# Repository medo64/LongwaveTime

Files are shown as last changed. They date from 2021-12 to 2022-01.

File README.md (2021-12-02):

[LongwaveTime](https://medo64.com/longwavetime/)
================================================

This USB device will show up on your system as a serial device and allow for
modulation of WWVB and DCF77 time synchronization signal using either onboard
or external antenna.

Actual antenna output stage is a variation on well-known [Radio time station
transmitter by Henner Zeller](https://github.com/hzeller/txtempus) setup which
sends the signal out with a bare minimum of components. Combine that rather
simplistic design with PCB antenna and you have yourself a really localized
device.

Mind you, this is by design as the primary use case for this device is
experimentation and it's not intended to compete with official WWVB or DCF77
signal. Onboard antenna should have enough power to work with watch on top of
it and no more.

Of course, with an external 60 kHz (WWVB) or 75 kHz (DCF77) antenna, signal will
propagate a bit further but you should really only consider this if your home
is not covered with official signal.

### Legality of WWVB transmission ###

Transmitting on unlicensed frequencies is quite often an issue and should be
taken seriously. In USA legality of the same is coverted in [Understanding the FCC Regulations for Low-Power Non-Licensed Transmitters](https://transition.fcc.gov/Bureaus/Engineering_Technology/Documents/bulletins/oet63/oet63rev.pdf).
Short version is that you can do so as long as you keep it under 40 μV/m
measured at 300 meters. This device with its internal antenna is going to be
way under this limit.

If you plan to use it with external antenna, things get a bit trickier. I like
to use NIST's [Estimated Seasonal Signal Strength of WWVB, µV/m](https://www.nist.gov/system/files/documents/calibrations/sp432-02.pdf)
as a rule-of-the-thumb reference and as long as your watch synchronization
works only up to 10 meteres or so, you will be way under 40 µV/m as required
by FCC's rules and really unlikely to be causing any interference.

But, regardless of the rules, under no circumstances should you interfere with
official WWVB signal. This might not be encoded in rules, but it should be a
common sense.

As far as legality in other countries goes, do your own research.

---
*You can check my blog and other projects at [www.medo64.com](https://medo64.com/electronics/).*

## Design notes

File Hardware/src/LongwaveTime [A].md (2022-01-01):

### Longwave Time Parts ###

|  # | Part | RefDes  | DigiKey Part Number | Alternative Part Number |
|---:|---|---|---|---|
|  3 | C 560pF X7R 16V (0805) | C1-C3 | 1276-1798-1-ND | 1276-1834-1-ND |
|  2 | C 330nF X7R 16V (0805) | C4-C5 | 732-7669-1-ND | 1276-1123-1-ND |
|  2 | DS LED (0805) | DS1-DS2 | 475-1278-1-ND | L171L-LWC-TR |
|  1 | J USB B, horizontal | J1 | ED2982-ND | ED2983-ND |
|  3 | R 470 0.125W (0805) | R1-R3 | RMCF0805FT470RCT-ND | RMCF0805JT470RCT-ND |
|  4 | R 5.1K 0.125W (0805) | R4-R7 | RMCF0805FT5K10CT-ND | RMCF0805JT5K10CT-ND |
|  1 | U PIC16F1454-I/SL (SOIC-14) | U1 | PIC16F1454-I/SL-ND | PIC16F1454T-I/SLCT-ND |
|  1 | H Enclosure 4.5x1.4x1.0" | | HM861-ND | 377-1653-ND |
|  4 | H PCB Screw Self-tapping M3 6mm (#4 1/4") | | | |

#### Board Size ####

| | Dimensions | Area | Thickness |
|---|---|---|---|
| PCB |  85.4 x 26.0 mm | 3.5 in² | 1.6 mm |
| Panel |  29.5 x 20.3 mm | 1.0 in² | 1.6 mm |

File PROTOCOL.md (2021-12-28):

### Longwave Time Protocol ###

This device presents itself as a serial port. Serial port parameters are
115200,N,8,1.

For purpose of protocol `<CR>` and `<LF>` end of line characters can be used
interchangeably. Each response will end with `<CR><LF>`. If command has no
arguments, it will return the current status.

Commands that resulted in error will always end in `!` `<BEL>` `<CR>` `<LF>`.

#### Set Protocol (P) #####

This command will set the protocol.

| | Text |
|---|---|
| Syntax | `P{1:protocol}<LF>` |
| Response | `P{1:protocol}<CR><LF>` |
| Reject | `P!<BEL><CR><LF>` |

The following protocol values are allowed:

| Value | Protocol |  Carrier | Frequency |
|:-----:|---|---:|---:|
| 0 | None | - | - |
| W | WWVB | 60.0 kHz | 60,000.00 Hz |
| D | DCF77 | 77.5 kHz | 77,419.35 Hz |
| M | MSF | 60.0 kHz | 60,000.00 Hz |
| 4 | JJY | 40.0 kHz | 40,000.00 Hz |
| 6 | JJY | 60.0 kHz | 60,000.00 Hz |

Please note that 77.5 kHz cannot be correctly represented by device without a
small carrier deviation. This does not impact auto-incrementing time but only
the carrier. All watches I tested with were able to tolerate this.

Here are some usage examples:

| Example | Send | Receive | Notes |
|---|---|---|---|
| Query | `P<LF>` | `PW<CR><LF>` | Using WWVB protocol |
| Set WWVB | `PW<LF>` | `PW<CR><LF>` | Set protocol to WWVB |
| Set DCF77 | `PD<LF>` | `PD<CR><LF>` | Set protocol to DCF77 |
| Turn off | `P0<LF>` | `P0<CR><LF>` | No carrier or time-keeping |
| Unknown protocol | `Px<LF>` | `F!<BEL><CR><LF>`  | |

#### Raw Data (R) #####

Sets bit data. Data is always set for the buffer not in use.

Buffers are called X and Y.

| | Text | Notes |
|---|---|---|
| Syntax | `R{59-61:data}<LF>` | |
| Response | `R{2:buffer}<CR><LF>` | Current buffer, followed by buffer user for command |
| Reject | `R!<BEL><CR><LF>` | |

If one sets 59 or 61 bit, leap second will be assumed.

Bits sets using this command superseed data set by any other command.

The following bits are supported for [WWVB](https://en.wikipedia.org/wiki/WWVB):

| Data  | Value | Description |
|:-----:|---|---|
| 0 | Bit 0 | 200 ms reduced power, 800 ms full power |
| 1 | Bit 1 | 500 ms full power, 500 ms reduced power |
| M | Marker | 800 ms reduced power, 200 ms full power |

The following bits are supported for [DCF77](https://en.wikipedia.org/wiki/DCF77):

| Data  | Value | Description |
|:-----:|---|---|
| 0 | Bit 0 | 100 ms reduced power, 900 ms full power |
| 1 | Bit 1 | 200 ms reduced power, 800 ms full power |
| M | Minute mark  | no amplitude modulation |

The following bits are supported for [MSF](https://en.wikipedia.org/wiki/Time_from_NPL_(MSF)):

| Data  | Value | Description |
|:-----:|---|---|
| 0 | Bits 00 | Carrier is encoded as follows _~~~~~~~~~ |
| 1 | Bits 01 | Carrier is encoded as follows _~_~~~~~~~ |
| 2 | Bits 10 | Carrier is encoded as follows __~~~~~~~~ |
| 3 | Bits 11 | Carrier is encoded as follows ___~~~~~~~ |
| M | Minute mark  | Carrier off for 500 ms, carrier on for 500 ms |

The following bits are supported for [JJY](https://en.wikipedia.org/wiki/JJY):

| Data  | Value | Description |
|:-----:|---|---|
| 0 | Bit 0 | 800 ms full power, 200 ms reduced power |
| 1 | Bit 1 | 500 ms full power, 500 ms reduced power |
| M | Marker | 200 ms full power, 800 ms reduced power |

Here are some usage examples:

| Example | Send | Receive | Notes |
|---|---|---|---|
| Query | `R<LF>` | `RYX<CR><LF>` | Buffer Y is currently in use and X is ready |
| Query | `R<LF>` | `RY~<CR><LF>` | Buffer Y is currently in use and no new buffer is ready |
| Set | `R123...<LF>` | `R~X<CR><LF>` | New data was written in buffer X and there was no current buffer |
| Not enough bits | `R011<LF>` | `R!<BEL><CR><LF>`  | Must have 59-61 bits (60 usually) |
| Unknown protocol | `Rx<LF>` | `R!<BEL><CR><LF>`  | |

#### Start (S) #####

This command will synchronize time and start sending data if one is not already
sent. Input can be given in either seconds or tenths of second while output is
always in tenths of second.

Buffer is always switched either when `S` is called or when a full minute has
elapsed.

| | Text |
|---|---|
| Syntax | `S{2-3:second}<LF>` |
| Response | `S{3:second}<CR><LF>` |
| Reject | `S!<BEL><CR><LF>` |

Second can be any number from 00-60.

Here are some usage examples:

| Example | Send | Receive | Notes |
|---|---|---|---|
| Query | `S<LF>` | `S103<CR><LF>` | Returns current tenth of a second (10.2s) |
| Query | `S<LF>` | `S---<CR><LF>` | Returning `-` when not active |
| Sync time | `S42<LF>` | `S420<CR><LF>` | Syncs device to second 42 |
| Unknown second | `S61<LF>` | `S!<BEL><CR><LF>`  | |

##### Test Mode (T) #####

Testing. To enter into test mode use `T**<LF>`.

| | Text |
|---|---|
| Syntax | `T<LF>` |
| Response | `T{1:command}<CR><LF>` |
| Reject | `T!<BEL><CR><LF>` |

Here are some usage examples:

| Example | Send | Receive | Notes |
|---|---|---|---|
| Query | `T<LF>` | `TWCa<CR><LF>` | WWVB with clock but no attenuation |
| No protocol | `T0<LF>` | `T0Ca<CR><LF>` | No protocol with clock but no attenuation |
| WWVB protocol | `TW<LF>` | `TWCa<CR><LF>` | WWVB with clock but no attenuation |
| DCF77 protocol | `TD<LF>` | `TDCa<CR><LF>` | DCF77 with clock but no attenuation |
| MSF protocol | `TM<LF>` | `TMCa<CR><LF>` | MSF with clock but no attenuation |
| JJY40 protocol | `T4<LF>` | `T4Ca<CR><LF>` | JJY40 with clock but no attenuation |
| JJY60 protocol | `T6<LF>` | `T6Ca<CR><LF>` | JJY60 with clock but no attenuation |
| Enable clock | `TC<LF>` | `TWCa<CR><LF>` | WWVB with clock but no attenuation |
| Disable clock | `Tc<LF>` | `TWca<CR><LF>` | WWVB without clock and no attenuation |
| Enable attenuation  | `TA<LF>` | `TWCA<CR><LF>` | WWVB with clock and attenuation |
| Disable attenuation | `Ta<LF>` | `TWca<CR><LF>` | WWVB without clock and no attenuation |
| Output radio signal | `TO<LF>` | `TWCa<CR><LF>` | Outputs debug signal |
| Reboot | `T-<LF>` | Nothing | Reboots the device |
| Unknown parameters  | `Tx<LF>` | `T!<BEL><CR><LF>`  | |

##### Version (V) #####

Returns software version.

| | Text |
|---|---|
| Syntax | `V<LF>` |
| Response | `V{2:major}.{2:minor}<CR><LF>` |
| Reject | `V!<BEL><CR><LF>` |

Here are some usage examples:

| Example | Send | Receive | Notes |
|---|---|---|---|
| Query | `V<LF>` | `V2112<CR><LF>` | Version is 21.12 |
| Unknown parameters | `Vx<LF>` | `V!<BEL><CR><LF>`  | |

### Example Flow ###

When starting up:
  1) Set protocol using `P` command
  2) Set data for the current minute using `R` command (assuming second is <59)
  3) Wait for the start of next second and use `S` command to synchronize time

For the every minute after startup:
  1) At second `59` set data for the next minute using `R` command
  2) At second `00` apply new data using `S` command
  3) Rinse & repeat

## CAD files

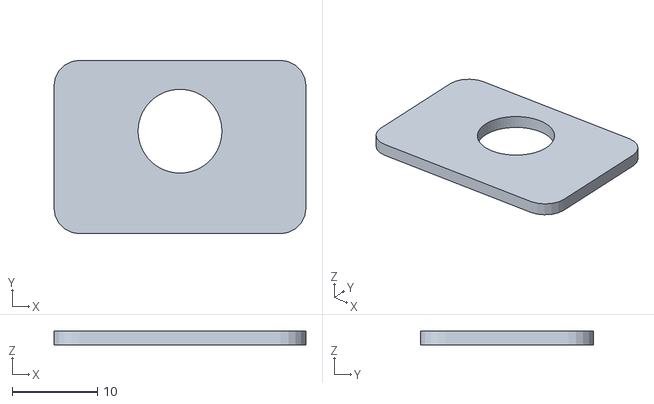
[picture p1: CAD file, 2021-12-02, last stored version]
Hardware/src/LongwaveTime [A] Panel (Antenna).stl
29.5 x 20.3 x 1.60

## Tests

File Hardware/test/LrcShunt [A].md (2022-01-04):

### LRC Shunt ###

#### Board Size ####

| | Dimensions | Area | Thickness |
|---|---|---|---|
| PCB |  51.0 x 17.0 mm | 1.4 in² | 0.8 mm |

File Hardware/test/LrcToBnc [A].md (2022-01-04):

### LRC To BNC ###

|  # | Part | RefDes  |
|---:|---|---|
|  1 | J BNC male | J1 |

Wires from 4-pin JST XH connector are terminated into 2-pin Dupont connector
as pairs 1-2 and 3-4.

#### Board Size ####

| | Dimensions | Area | Thickness |
|---|---|---|---|
| PCB |  51.0 x 25.0 mm | 2.0 in² | 0.8 mm |

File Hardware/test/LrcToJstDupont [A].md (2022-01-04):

### LRC To DuPont ###

|  # | Part | RefDes  |
|---:|---|---|
|  1 | J JST XH 2.54mm (4w) | J1 |
|  1 | P Dupont 2.54mm (2w) | P1 |
|  1 | W Cable | |

Wires from 4-pin JST XH connector are terminated into 2-pin Dupont connector
as pairs 1-2 and 3-4.

#### Board Size ####

| | Dimensions | Area | Thickness |
|---|---|---|---|
| PCB |  51.0 x 22.0 mm | 1.8 in² | 0.8 mm |

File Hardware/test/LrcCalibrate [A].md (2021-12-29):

### LRC Calibrate ###

#### Board Size ####

| | Dimensions | Area | Thickness |
|---|---|---|---|
| PCB |  32.0 x 13.0 mm | 0.7 in² | 1.6 mm |

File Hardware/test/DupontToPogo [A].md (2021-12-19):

### DuPont To Pogo ###

|  # | Part | RefDes  |
|---:|---|---|
|  1 | J JST XH 2.54mm (4w) | J1 |
|  2 | TP Pogo (1w) | TP1-TP2 |

#### Board Size ####

| | Dimensions | Area | Thickness |
|---|---|---|---|
| PCB |  18.0 x 12.0 mm | 0.4 in² | 1.6 mm |

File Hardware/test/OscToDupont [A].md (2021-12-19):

### Oscilloscope To DuPont ###

|  # | Part | RefDes  |
|---:|---|---|
|  2 | J BNC male | J1-J2 |
|  1 | J JST XH 2.54mm (4w) | J3 |
|  1 | P Dupont 2.54mm (2w) | P1 |
|  1 | W Cable | |

Wires from 4-pin JST XH connector are terminated into 2-pin Dupont connector
as pairs 1-2 and 3-4.

#### Board Size ####

| | Dimensions | Area | Thickness |
|---|---|---|---|
| PCB |  28.0 x 23.0 mm | 1.0 in² | 1.6 mm |

### Usage ###

Connect signal generator to `SIG`, spectrum analyzer to `OSC`, and remaining
connector to PCB. Generate 60 kHz square wave and use spectrum analyzer to see
where the dip happens.

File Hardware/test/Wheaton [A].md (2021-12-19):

### Wheaton ###

|  # | Part | RefDes  |
|---:|---|---|
|  4 | J BNC male | J1-J4 |

#### Board Size ####

| | Dimensions | Area | Thickness |
|---|---|---|---|
| PCB |  28.0 x 28.0 mm | 1.3 in² | 1.6 mm |

### Usage ###

Connect signal generator to `SIG`, oscilloscope to `REF` and `VAR`, and
remaining `ANT` connector to antenna. Generate 60 kHz sine wave and align
`REF` and `VAR` waveforms as closely as possible.

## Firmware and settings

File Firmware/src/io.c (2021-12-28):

#include <xc.h>
#include <stdint.h>
#include "io.h"
#include "system.h"


void io_init(void) {
    // Activity
    LATC2 = 1;   // default to off (inverse)
    TRISC2 = 0;  // enable output
    
    // PPS
    LATA5 = 1;   // default to off (inverse)
    TRISA5 = 0;  // enable output
    
    // Tick
    LATC5 = 0;   // default to off
    TRISC5 = 0;  // enable output

    // Clock
    LATC3 = 0;   // default to off
    TRISC3 = 1;  // keep tri-state (sorted in io_clock_setup)

    // Attenuation
    LATC4 = 0;   // it'll be always off
    TRISC4 = 1;  // keep tri-state
}

void io_splash(void) {
    io_led_activity_on(); wait_short();
    io_led_pps_on(); io_led_activity_off(); wait_short();
    io_led_activity_on(); io_led_pps_off(); wait_short();
    io_led_pps_on(); io_led_activity_off(); wait_short();
    io_led_pps_off(); io_led_activity_on();
}


#define LED_ACTIVITY_TIMEOUT       2000
#define LED_ACTIVITY_TIMEOUT_NONE  65535
uint16_t LedAcivityTimeout = LED_ACTIVITY_TIMEOUT_NONE;

void io_led_activity_tick(void) {
    if (LedAcivityTimeout != LED_ACTIVITY_TIMEOUT_NONE) {
        if (LedAcivityTimeout == 0) {
            io_led_activity_on();
            LedAcivityTimeout = LED_ACTIVITY_TIMEOUT_NONE;
        } else {
            LedAcivityTimeout--;
        }
    }
}

void io_led_activity_blink(void) {
    io_led_activity_off();
    LedAcivityTimeout = LED_ACTIVITY_TIMEOUT;
}


uint16_t io_clock_setup40khz(void) {
    PWM2CONbits.PWM2OE = 0;               // 1: Disable the PWM0 pin output driver
    PWM2CON = 0;                          // 2: Clear the PWMxCON register
    PR2 = 0b01001010;                     // 3: Load the PR2 register with the PWM period value
    PWM2DCH = 0; PWM2DCL = 0;             // 4: Clear the PWMxDCH register and bits <7:6> of the PWMxDCL register
    T2CON = 0b01111101;                   // 5: Configure and start Timer2 (1:4 prescaler, 1:16 postscaler)
    PWM2CONbits.PWM2EN = 1;               // 6: Enable PWM output pin
    PWM2CONbits.PWM2OE = 1;               // 7: Enable the PWMx pin output driver
    PWM2DCH = 37; PWM2DCL = 0b10000000;   // 4∗(PR2+1)∗DutyCycleRatio - 150
    return 250;                           // 100/((1/40000)*16*1000)
}

uint16_t io_clock_setup60khz(void) {
    PWM2CONbits.PWM2OE = 0;               // 1: Disable the PWM0 pin output driver
    PWM2CON = 0;                          // 2: Clear the PWMxCON register
    PR2 = 0b11000111;                     // 3: Load the PR2 register with the PWM period value
    PWM2DCH = 0; PWM2DCL = 0;             // 4: Clear the PWMxDCH register and bits <7:6> of the PWMxDCL register
    T2CON = 0b01111100;                   // 5: Configure and start Timer2 (1:1 prescaler, 1:16 postscaler)
    PWM2CONbits.PWM2EN = 1;               // 6: Enable PWM output pin
    PWM2CONbits.PWM2OE = 1;               // 7: Enable the PWMx pin output driver
    PWM2DCH = 100; PWM2DCL = 0b00000000;  // 4∗(PR2+1)∗DutyCycleRatio - 400
    return 375;                           // 100/((1/60000)*16*1000)
}

uint16_t io_clock_setup77khz(void) {
    PWM2CONbits.PWM2OE = 0;               // 1: Disable the PWM0 pin output driver
    PWM2CON = 0;                          // 2: Clear the PWMxCON register
    PR2 = 0b10011010;                     // 3: Load the PR2 register with the PWM period value
    PWM2DCH = 0; PWM2DCL = 0;             // 4: Clear the PWMxDCH register and bits <7:6> of the PWMxDCL register
    T2CON = 0b01101100;                   // 5: Configure and start Timer2 (1:1 prescaler, 1:14 postscaler)
    PWM2CONbits.PWM2EN = 1;               // 6: Enable PWM output pin
    PWM2CONbits.PWM2OE = 1;               // 7: Enable the PWMx pin output driver
    PWM2DCH = 77; PWM2DCL = 0b10000000;   // 4∗(PR2+1)∗DutyCycleRatio - 310
    return 553;                           // 100/((1/77419.35)*14*1000)
}

void io_clock_on(void) {
    INTCONbits.PEIE = 1;    // enable peripheral interrupts
    INTCONbits.GIE = 1;     // enable global interrupts
    PIR1bits.TMR2IF = 0;    // reset interrupt flag
    PIE1bits.TMR2IE = 1;    // enable interrupt
    PWM2CONbits.PWM2OE = 1; // enable PWM
    TRISCbits.TRISC3 = 0;   // enable output
}

void io_clock_off(void) {
    PWM2CONbits.PWM2OE = 0; // enable PWM
    TRISCbits.TRISC3 = 1;   // disable output
}

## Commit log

2021-12-02 Added 3D print antenna panel
    [LongwaveTime [A] Panel (Antenna).stl]
2021-12-02 Changed USB connector and PIC to easier-to-solder package
    [LongwaveTime [A] Panel (Antenna).stl]
2021-12-02 Shortened board not to use full width
2021-12-19 Added test boards
2021-12-20 Lowering antenna turn count
2021-12-24 Refactored antenna to be 45x24mm
2021-12-24 Refactoring activity LED
2021-12-24 Refactoring solder mask over antenna
2021-12-24 Fixed PWM duty cycle
    [io.c]
2021-12-29 Updated component values and silkscreen
2021-12-30 Added outlines for resistors and capacitors
2022-01-01 Refactored for low-pass filtering
2022-01-04 Updated LRC connector to include shield
2022-01-17 Changing antenna connector orientation
